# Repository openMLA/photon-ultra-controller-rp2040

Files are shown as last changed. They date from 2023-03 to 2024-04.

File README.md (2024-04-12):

> [!IMPORTANT]
> This repository has been archived as the implementation turned out to have too many limitations regarding memory. It will work for 2-bit images, but the newer approach is all around more capable. The replacement approach uses the DPI of a raspberry pi, and can be found at [openMLA/photon-ultra-controller](https://github.com/openMLA/photon-ultra-controller)

# Photon Ultra DLP controller

This repository contains PCB design files and code for a replacement mainboard for the [Anycubic Photon Ultra](https://www.anycubic.com/pages/anycubic-photon-ultra). 

The replacement board allows users to generate the signals required for the *DLP controller board* (designed by eViewTek) & DMD that comes with the photon ultra. It does not capture the full functionality of the Anycubic mainboard as it does not control the interface LCD, control the mechanics (stepper motor) or run any resin 3D printer slicer software. It **only** controls the DLP projector with an arbitrary 2-bit* 1240x720 image. Exposure time can be set per image.

This project might be of interest to you if you **own a photon ultra** and are interested in either

1. Using the photon ultra for PCB fabrication (use the DLP to expose a photoresist)
2. Are looking to use a DMD for other applications but are not ready to build your own controller board.

If you are interested in learning more about the Photon Ultra, you can find more information on [this photon ultra teardown blog post](https://nemoandrea.github.io/blog/Anycubic_DLP_teardown/). More images are available on request.

> If you have another board that uses the DMD chipset (e.g. Anycubic D2 or Mars 4 DLP), you can probably modify the project with minimal effort and get it to work for those boards too! (you would have to maybe have to adjust the traces to the FPC, and maybe tweak the physical connectors etc; but code and approach would be very similar)

### 💡 UV Patterns

> [!NOTE]  
> Due to RAM limitations (and my c programming skill limitations) the board can only display 2-bit images if you use the full resolution of the DMD. More RAM would solve this issue.

Below an example of the eViewTek board and optical engine controlled by the pico pio units, showing the OpenMLA project logo. Note that the pattern is 2-bit, so there are only 4 intensities (of which 1 is OFF).

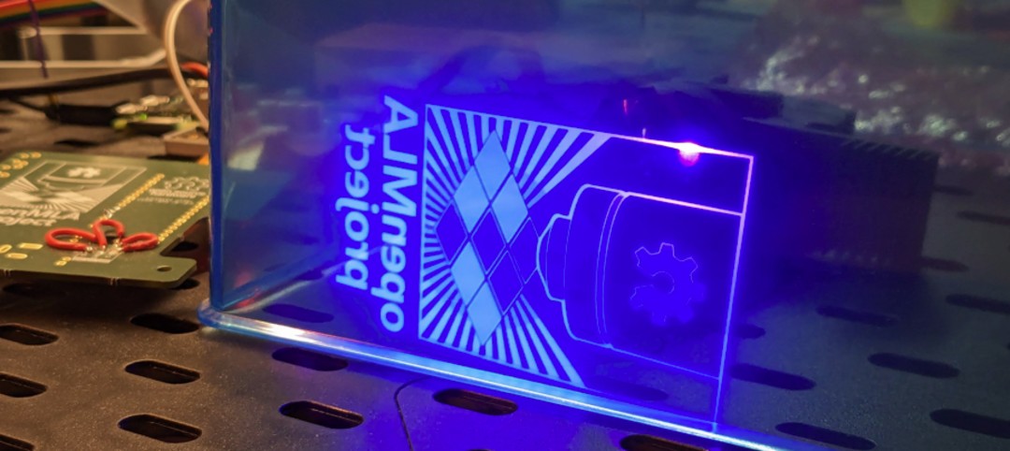
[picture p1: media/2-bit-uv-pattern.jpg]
image of projected UV light showing the logo of the openMLA project. The pattern is 2-bit.


Below another example of the 4 grayscale values that can be shown.

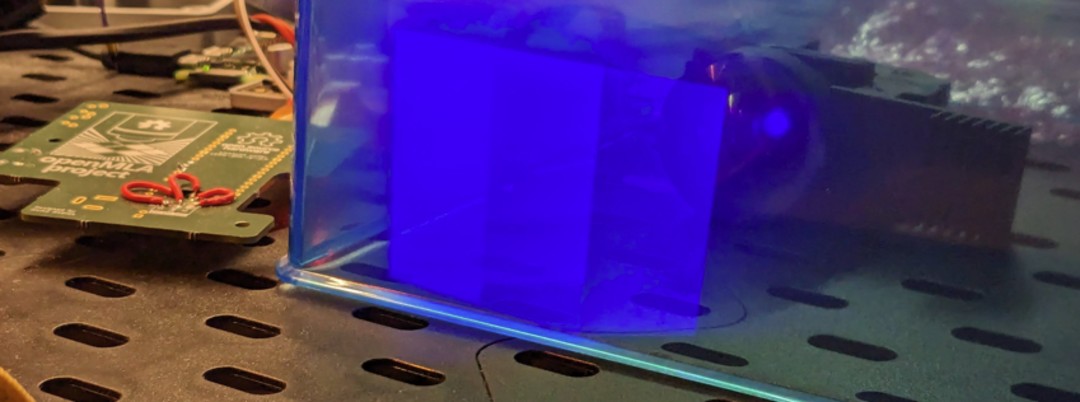
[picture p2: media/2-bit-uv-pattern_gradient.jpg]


### PCB

The PCB uses a Raspberry Pi Pico board as the central controller. The PIO blocks of the RP2040 generate the timing signals for the DLPC1438 chip on the DLP controller board.

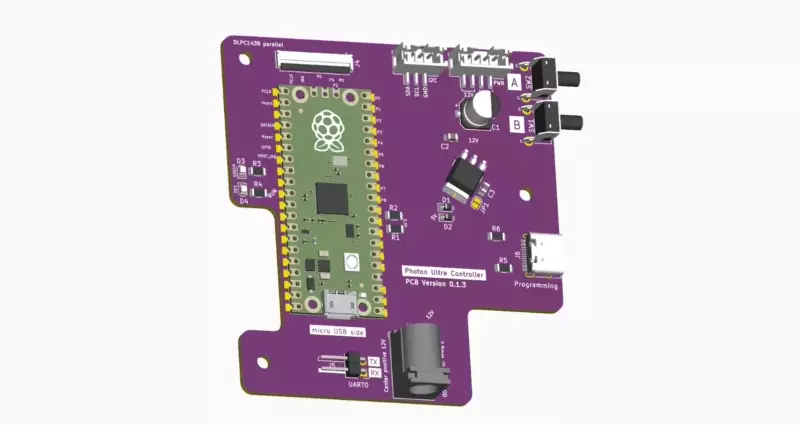
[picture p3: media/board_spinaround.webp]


### Using the board

The board is shaped to fit in the original mainboard space. The buttons, usb-c programming port and barrel jack are all accessible through the original Photon Ultra enclosure. This means you can use the original fittings, and everything in terms of cables should just fit.



Of course if you do not plan on using the DMD in the context of the photon ultra, you could easily redesign the board to be much more compact.

### Code

The code for this project is written in C, and unfortunately I am not a C programmer so it is very sloppy code. If you know of ways to make parts more elegant don't hesitate to make a pull request with changes.

More important than the code is the approach taken to power up and control the photon board, and more specifically the DLPC1438. A walkthrough of steps and gotchas can be found in [the guidelines](Guidelines.md). Most of it will also be mentioned in the code for the project, but having a separate document is more convenient.

The PIO implementation is a modified version of the nice [writeup by Hunter Adams](https://vanhunteradams.com/Pico/VGA/VGA.html#Code-organization).

To convert images for display, there is a simple python utility that converts a grayscale image into the right byte format for display. You can run it on the demo images to verify assembly.

### Context

This work was developed as part of the [openMLA project](https://github.com/openMLA), where the goal is to build an open hardware lithography system. Eventually an open hardware DLP controller board will be published as part of openMLA, but this represents an intermediate step. 

### Project TODO

* ✅ Establish I2C communication with DLPC1438 

* ✅ Verify UCB programming and linear regulator

* ❓ Verify 12V power delivery to board (should be fine as of version 0.1.4)

* ✅ Verify 51-pin connector and pinout is correct

* ✅ Verify (2-bit) images can be sent and projected

* ❓ Implement SPI interface for transferring images to the pico

* ❓ Minimise flickering

## Acknowledgements

The following KiCAD external libraries were used

* [Raspberry pi pico by ncarandini](https://github.com/ncarandini/KiCad-RP-Pico)

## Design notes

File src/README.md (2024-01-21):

## Running the DLP pico demo

To run the demo code on your pico, copy over the `build/DLP_pico.uf2` over to the pico.

### Building the demo code

I don't know a thing about compiling C stuff but given that this code is based on the nice [example code by Hunter Adams](https://vanhunteradams.com/Pico/VGA/VGA.html) most of the cmake stuff is already set up. To be able to build the project you may need to install the pico sdk. You can read more about this [in the official getting started guide](https://datasheets.raspberrypi.com/pico/getting-started-with-pico.pdf).

To build the project, head into the `build` directory and run

```
cmake .. -DPICO_BOARD=pico_w
```

and follow that up with 

```
make
```

Which should finally create the file `DLP_pico.uf2` that you can then use to program the pico. The `DLP_pico.uf2` file is also included in the repository to avoid having to go through the build process itself if you don't need to modify anything.

### Tools

In terms of hardware, I would suggest either using a [pico debug probe](https://www.raspberrypi.com/products/debug-probe/) to upload code, reset the pi and read the serial output, or a raspberry pi zero for the same application. You really don't want to have to unplug the board and press the reset button every time you want to try a new version of the code. Future versions of the board should make wiring SWD and UART readout easier.

I am not experienced enough with C to make a solid recommendation, but for the project I used Microsoft Visual Studio Code. With extensions:

* cmake
* serial monitor  (so we can get some information back from the pico)

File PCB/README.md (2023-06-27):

### PCB design

The design uses a Raspberry pi Pico W. A non-wireless version can also work but some of the scripts are to be built around wireless connectivity for data transfer. See the schematic (below and [as a pdf](schematic.pdf)) for more info.



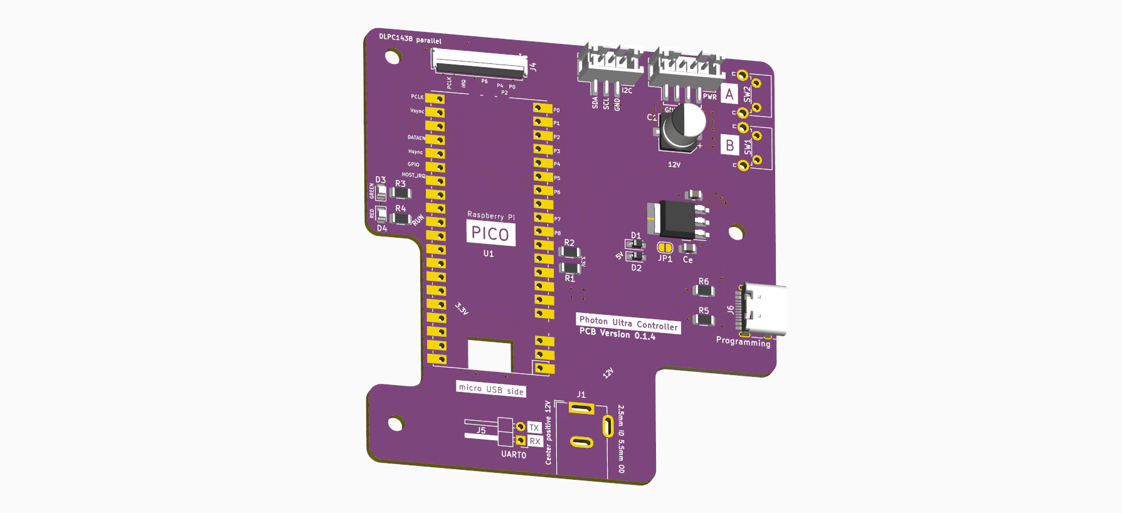
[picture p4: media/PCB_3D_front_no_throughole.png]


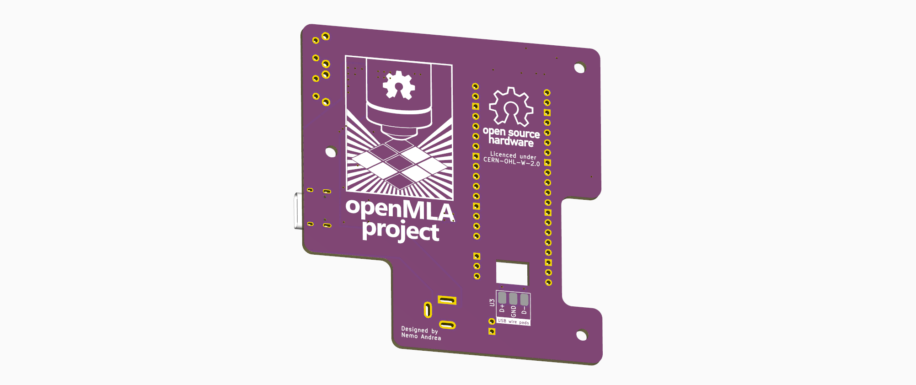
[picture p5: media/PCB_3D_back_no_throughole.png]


### Assembly

Most components are SMD, and the mouser links can be found in the basic [BOM](BOM.csv). In addition to the components of the BOM, you will also need some small wires to connect the USB data lines.

A solderpaste stencil might be worthwhile, as that FPC connector is pretty challenging (but not impossible) to handsolder.

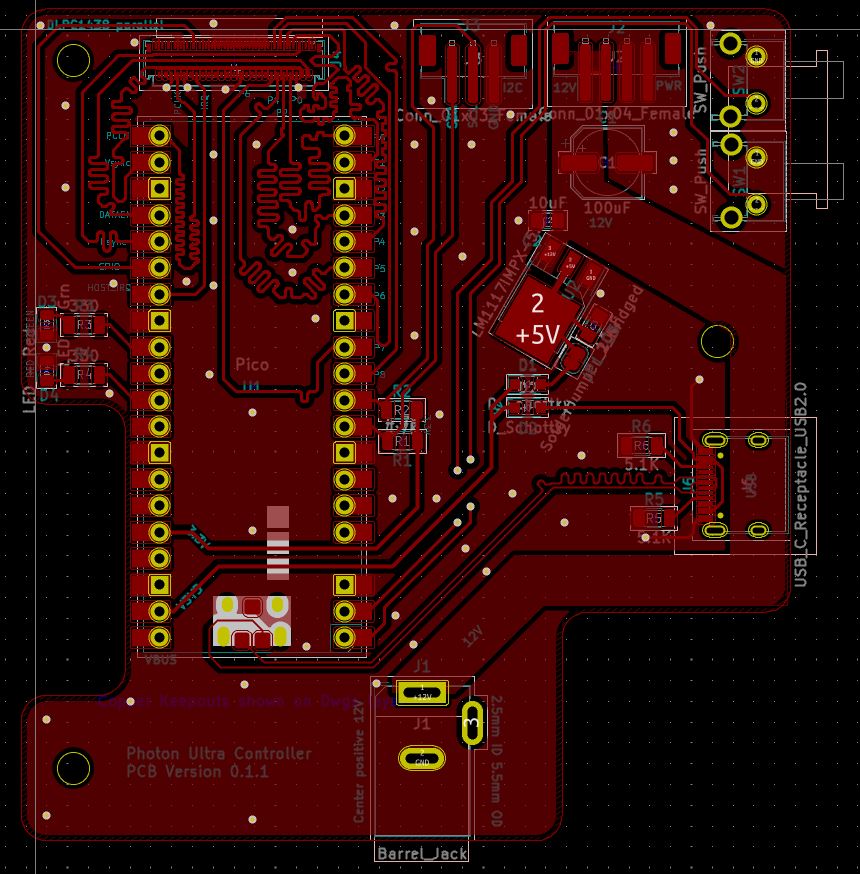
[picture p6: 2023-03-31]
media/PCB_preview.JPG

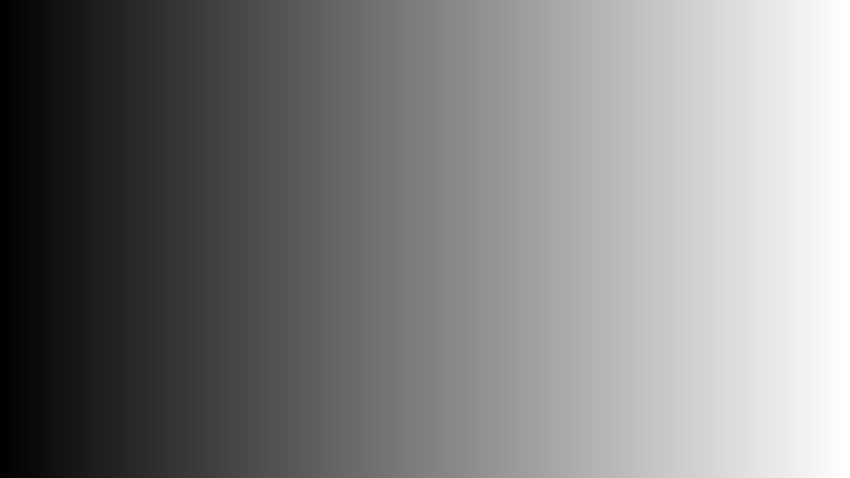
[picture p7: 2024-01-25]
utils/gradient_sample_image.tif

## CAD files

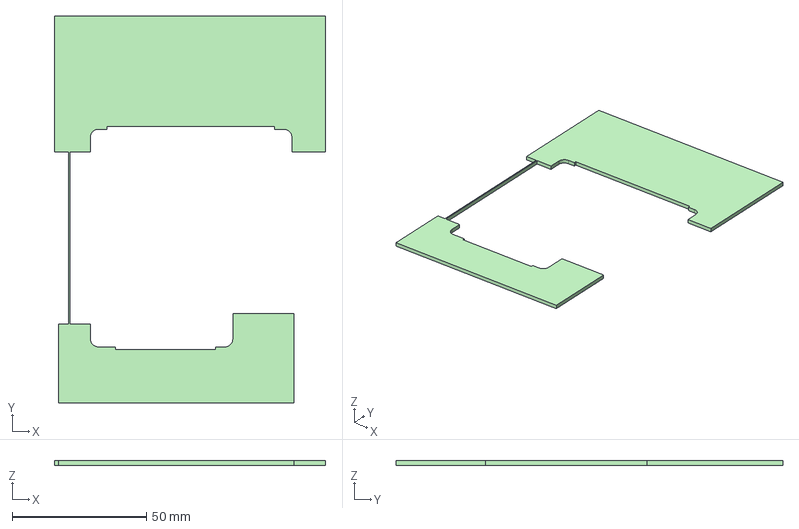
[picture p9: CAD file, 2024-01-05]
PCB/board-outline/board-outline-stencil-buffer.step
100.9 x 143.9 x 1.70 mm

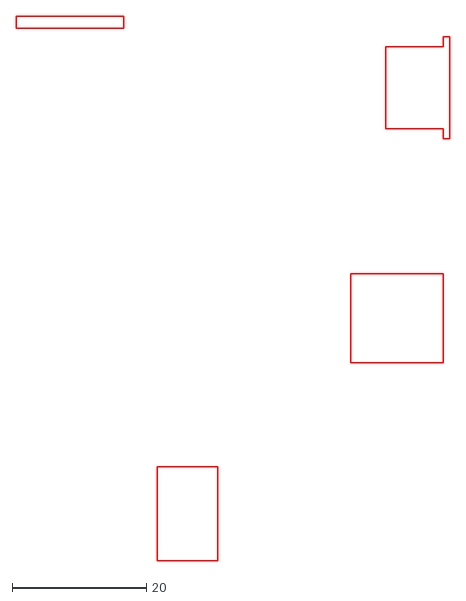
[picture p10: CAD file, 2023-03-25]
PCB/board-outline/board-outline-bits.dxf
64.5 x 81.1

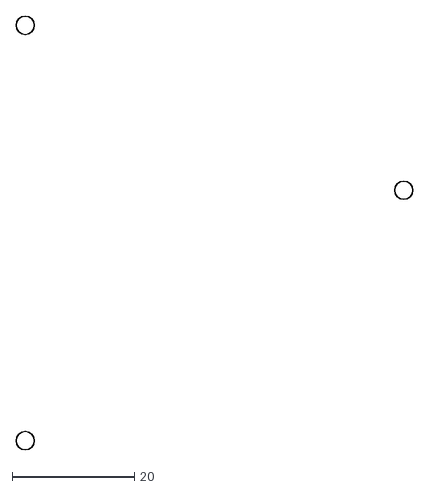
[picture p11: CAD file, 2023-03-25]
PCB/board-outline/board-outline-holes.dxf
65.0 x 71.0

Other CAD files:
PCB/board-outline/board-outline.FCStd
PCB/board-outline/board-outline.dxf

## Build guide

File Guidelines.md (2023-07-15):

## Photon Ultra board & DLPC1438 guidelines

> This section will outline some of the guidelines, and excerpts from the datasheets that are relevant to both specifically the Photon Ultra board and the DLPC1438 in general.

Suggested documents to familiarise yourself with

1. [The DLPC1438 datasheet](https://www.ti.com/lit/ds/symlink/dlpc1438.pdf?ts=1689232218137)
2. [The DLPC1438 programming guide (describes the I2C stuff)](https://www.ti.com/lit/ug/dlpu111/dlpu111.pdf?ts=1689282051632&ref_url=https%253A%252F%252Fwww.google.com%252F)
3. [The raspberry pi pico c SDK](https://datasheets.raspberrypi.com/pico/raspberry-pi-pico-c-sdk.pdf)

### Startup sequence

In the datasheet for the  `DLPC1438` there are multiple sections containing info about the startup sequence:

1. section 7.3.3
2. section 9.2 & 9.3

The main gist of it is that to power on you must both:

1. Provide power to the photon ultra board
2. Keep GPIO_08 (on DLPC1438) (a.k.a. PROJ_ON) high

The controller will then run through a reset/bootup cycle and eventually let you know it is done by pulling HOST_IRQ low.

After HOST_IRQ is low you can start the i2c bus and start talking to the DLPC1438.

> 🖼 Figure 9-1 of the datasheet nicely summarises this.

### I2C notes

For whatever reason (probably a I2C address conflict) Anycubic/eViewTek has changed the default i2c adress of the DLPC1438 on the Ultra's board from `0x36` to `0x1B`. 

> I assume this will be the same for all the boards, but if not you can connect power and the FPC to the ultra's mainboard and only the i2c line to the pico board and then after power on of the Ultra mainboard run an i2c scan script to find out the address of the DLPC1438.

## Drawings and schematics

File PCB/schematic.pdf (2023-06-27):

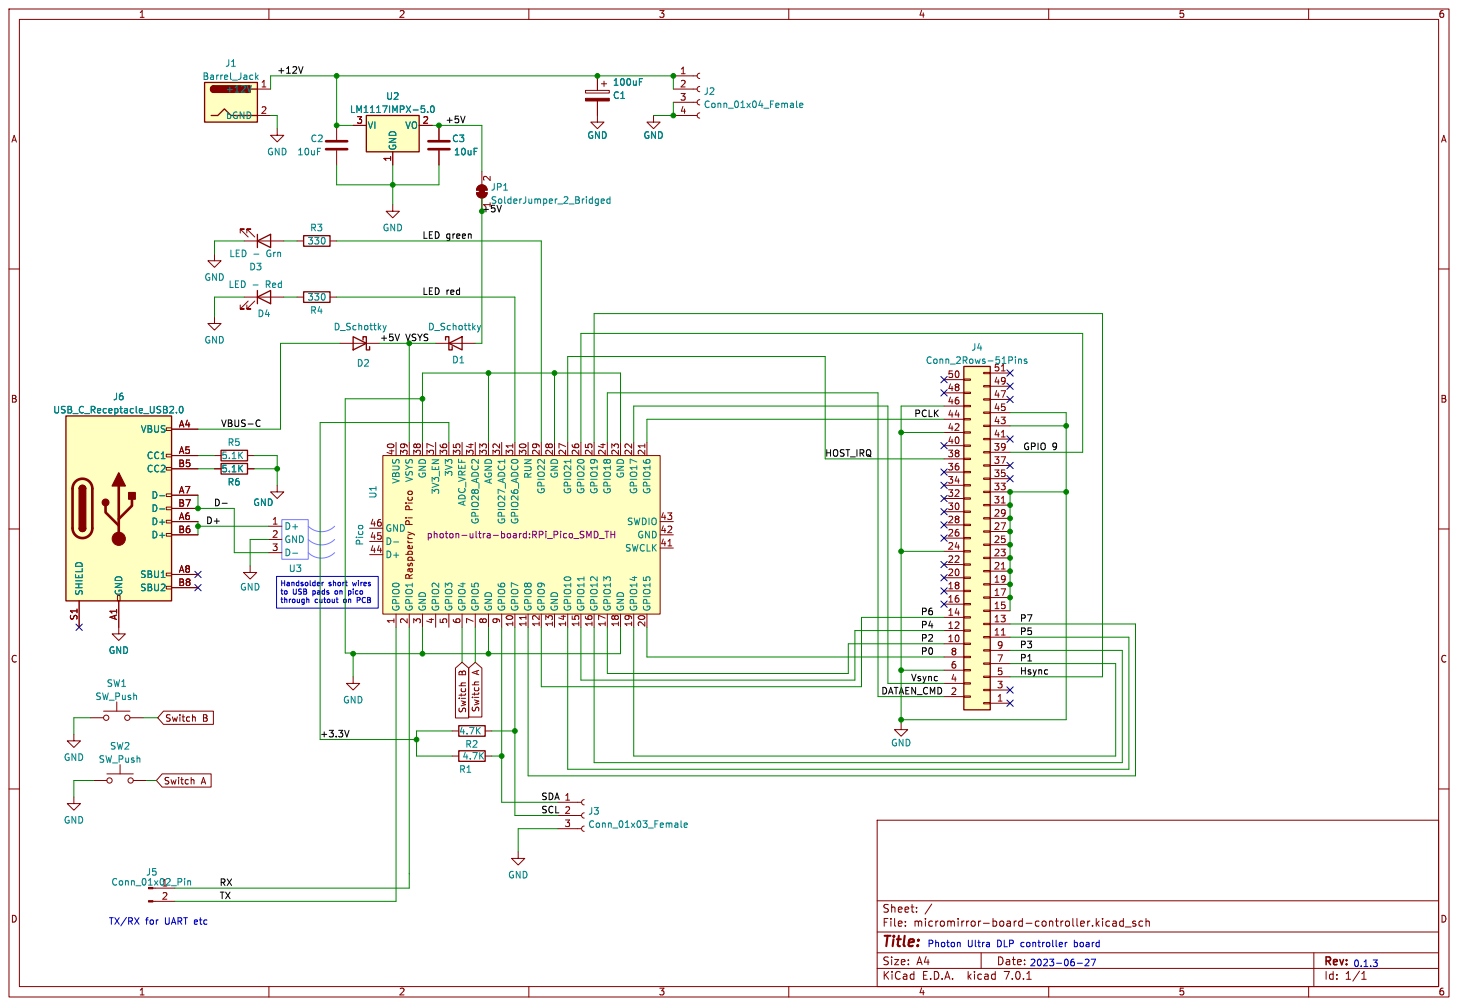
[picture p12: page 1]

to USB pads on pico
through cutout on PCB

Id: 1/1 Title: File: micromirror-board-controller.kicad_sch Sheet: /

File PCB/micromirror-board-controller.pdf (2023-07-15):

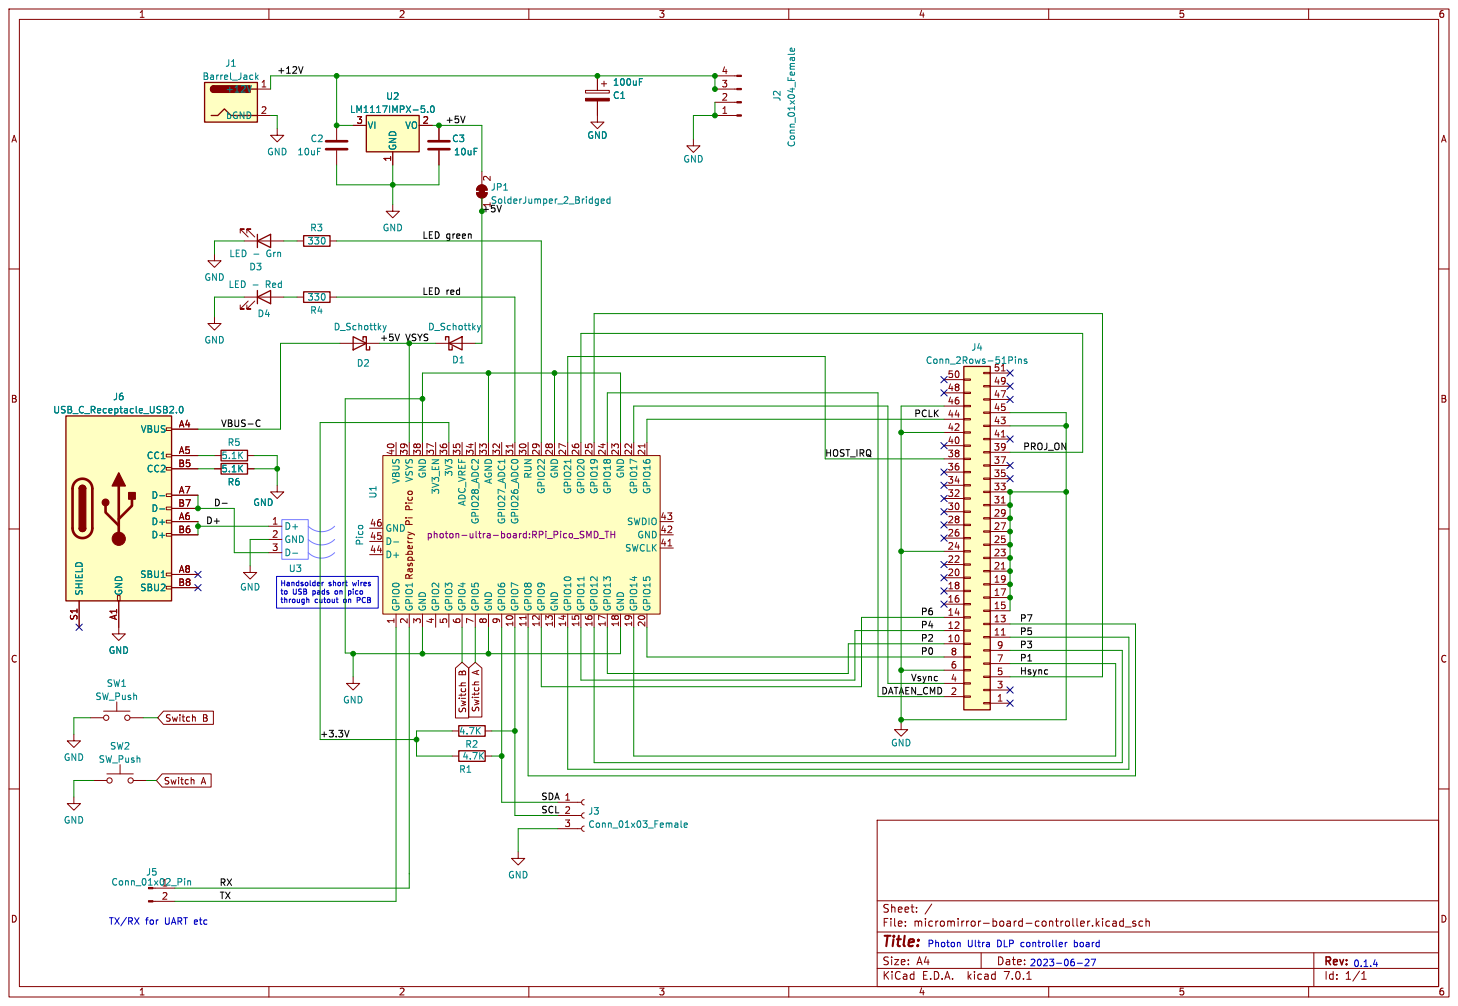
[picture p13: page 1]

to USB pads on pico

Id: 1/1 Title: File: micromirror-board-controller.kicad_sch Sheet: /

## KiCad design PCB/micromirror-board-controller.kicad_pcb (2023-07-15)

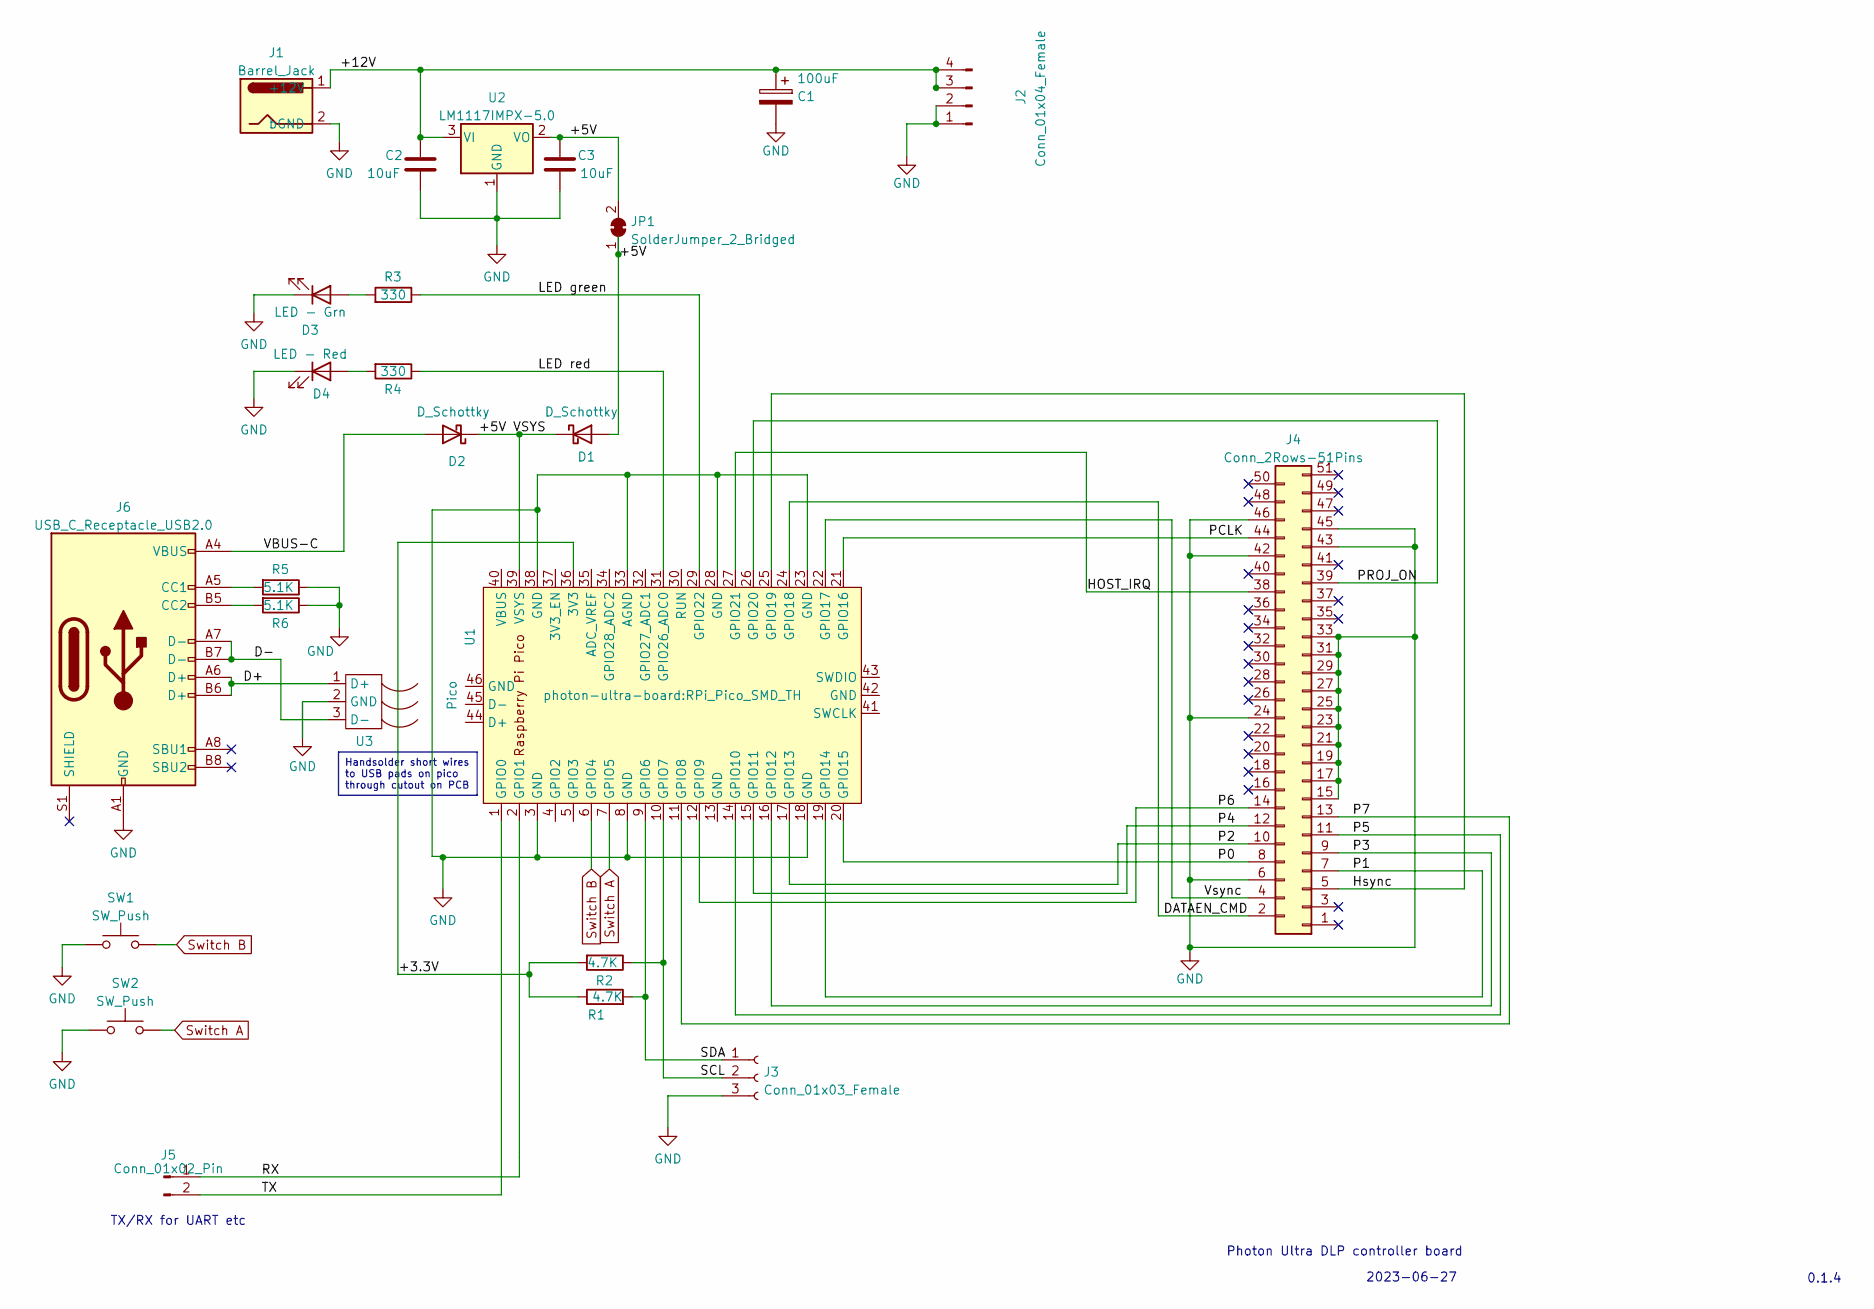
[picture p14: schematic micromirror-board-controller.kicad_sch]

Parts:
C1: 100uF; CP_Elec_6.3x7.7
C2, C3: 10uF; C_0805_2012Metric_Pad1.18x1.45mm_HandSolder
D1, D2: D_Schottky; D_SOD-323_HandSoldering
D3: LED - Grn; LED_0805_2012Metric
D4: LED - Red; LED_0805_2012Metric
J1: Barrel_Jack; BarrelJack_GCT_DCJ200-10-A_Horizontal
J2: Conn_01x04_Female; JST_PH_B4B-PH-SM4-TB_1x04-1MP_P2.00mm_Vertical
J3: Conn_01x03_Female; JST_PH_B3B-PH-SM4-TB_1x03-1MP_P2.00mm_Vertical
J4: Conn_2Rows-51Pins; Molex_502250-5191_2Rows-51Pins-1MP_P0.60mm_Horizontal
J5: Conn_01x02_Pin; PinHeader_1x02_P2.54mm_Horizontal
J6: USB_C_Receptacle_USB2.0; USB_C_Receptacle_HRO_TYPE-C-31-M-12
JP1: SolderJumper_2_Bridged; SolderJumper-2_P1.3mm_Bridged_RoundedPad1.0x1.5mm
R1, R2: 4.7K; R_1206_3216Metric
R3, R4: 330; R_1206_3216Metric
R5, R6: 5.1K; R_1206_3216Metric
SW1, SW2: SW_Push; SW_Tactile_SPST_Angled_PTS645Vx83-2LFS
U1: Pico; RPi_Pico_SMD_TH
U2: LM1117IMPX-5.0; TO-252-3_TabPin2
U3: usb-handsolder-pads

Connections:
/+3.3V: R1.1, R2.2, U1.36 (3V3)
/+5V: C3.1, D1.2 (A), JP1.1 (A), JP1.2 (B), U2.2 (VO); also elsewhere on the board
/+5V VSYS: D1.1 (K), D2.1 (K), U1.39 (VSYS)
/+12V: C1.1, C2.1, J1.1 (+12V), J2.3, J2.4, U2.3 (VI)
/D+: J6.A6 (D+), J6.B6 (D+), U3.1 (D+)
/D-: J6.A7 (D-), J6.B7 (D-), U3.3 (D-)
/DATAEN_CMD: J4.2 (DATAEN), U1.24 (GPIO18)
/HOST_IRQ: J4.38 (HOST_IRQ), U1.27 (GPIO21)
/Hsync: J4.5 (Hsync), U1.25 (GPIO19)
/LED green: R3.1, U1.29 (GPIO22)
/LED red: R4.1, U1.31 (GPIO26_ADC0)
/P0: J4.8 (P0), U1.20 (GPIO15)
/P1: J4.7 (P1), U1.19 (GPIO14)
/P2: J4.10 (P2), U1.17 (GPIO13)
/P3: J4.9 (P3), U1.16 (GPIO12)
/P4: J4.12 (P4), U1.15 (GPIO11)
/P5: J4.11 (P5), U1.14 (GPIO10)
/P6: J4.14 (P6), U1.12 (GPIO9)
/P7: J4.13 (P7), U1.11 (GPIO8)
/PCLK: J4.44 (PCLK), U1.21 (GPIO16)
/PROJ_ON: J4.39 (GPIO_9), U1.26 (GPIO20)
/RX: J5.1, U1.2 (GPIO1)
/SCL: J3.2 (SCL), R2.1, U1.10 (GPIO7)
/SDA: J3.1 (dGND), R1.2, U1.9 (GPIO6)
/TX: J5.2, U1.1 (GPIO0)
/VBUS-C: D2.2 (A), J6.A4 (VBUS), J6.A9 (VBUS), J6.B4 (VBUS), J6.B9 (VBUS)
/Vsync: J4.4 (Vsync), U1.22 (GPIO17)
GND: C1.2, C2.2, C3.2, D3.1 (K), D4.1 (K), J1.2 (bGND), J2.1, J2.2, J3.3 (SDA), J4.6 (GND), J4.15 (GND), J4.17, J4.19, J4.21, J4.23, J4.24, J4.25, J4.27, J4.29, J4.31, J4.33, J4.42 (GND), J4.43 (GND), J4.45 (GND), J4.46 (GND), J6.A1 (GND), J6.A12 (GND), J6.B1 (GND), J6.B12 (GND), R5.1, R6.1, SW1.1, SW2.1, U1.3 (GND), U1.8 (GND), U1.18 (GND), U1.23 (GND), U1.28 (GND), U1.33 (AGND), U1.38 (GND), U2.1 (GND), U3.2 (GND); also elsewhere on the board
unnamed: D3.2 (A), R3.2
unnamed: D4.2 (A), R4.2
unnamed: J6.A5 (CC1), R5.2
unnamed: J6.B5 (CC2), R6.2
Switch A: SW2.2, U1.7 (GPIO5)
Switch B: SW1.2, U1.6 (GPIO4)

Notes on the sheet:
Handsolder short wires to USB pads on pico through cutout on PCB
TX/RX for UART etc
Photon Ultra DLP controller board
2023-06-27
0.1.4

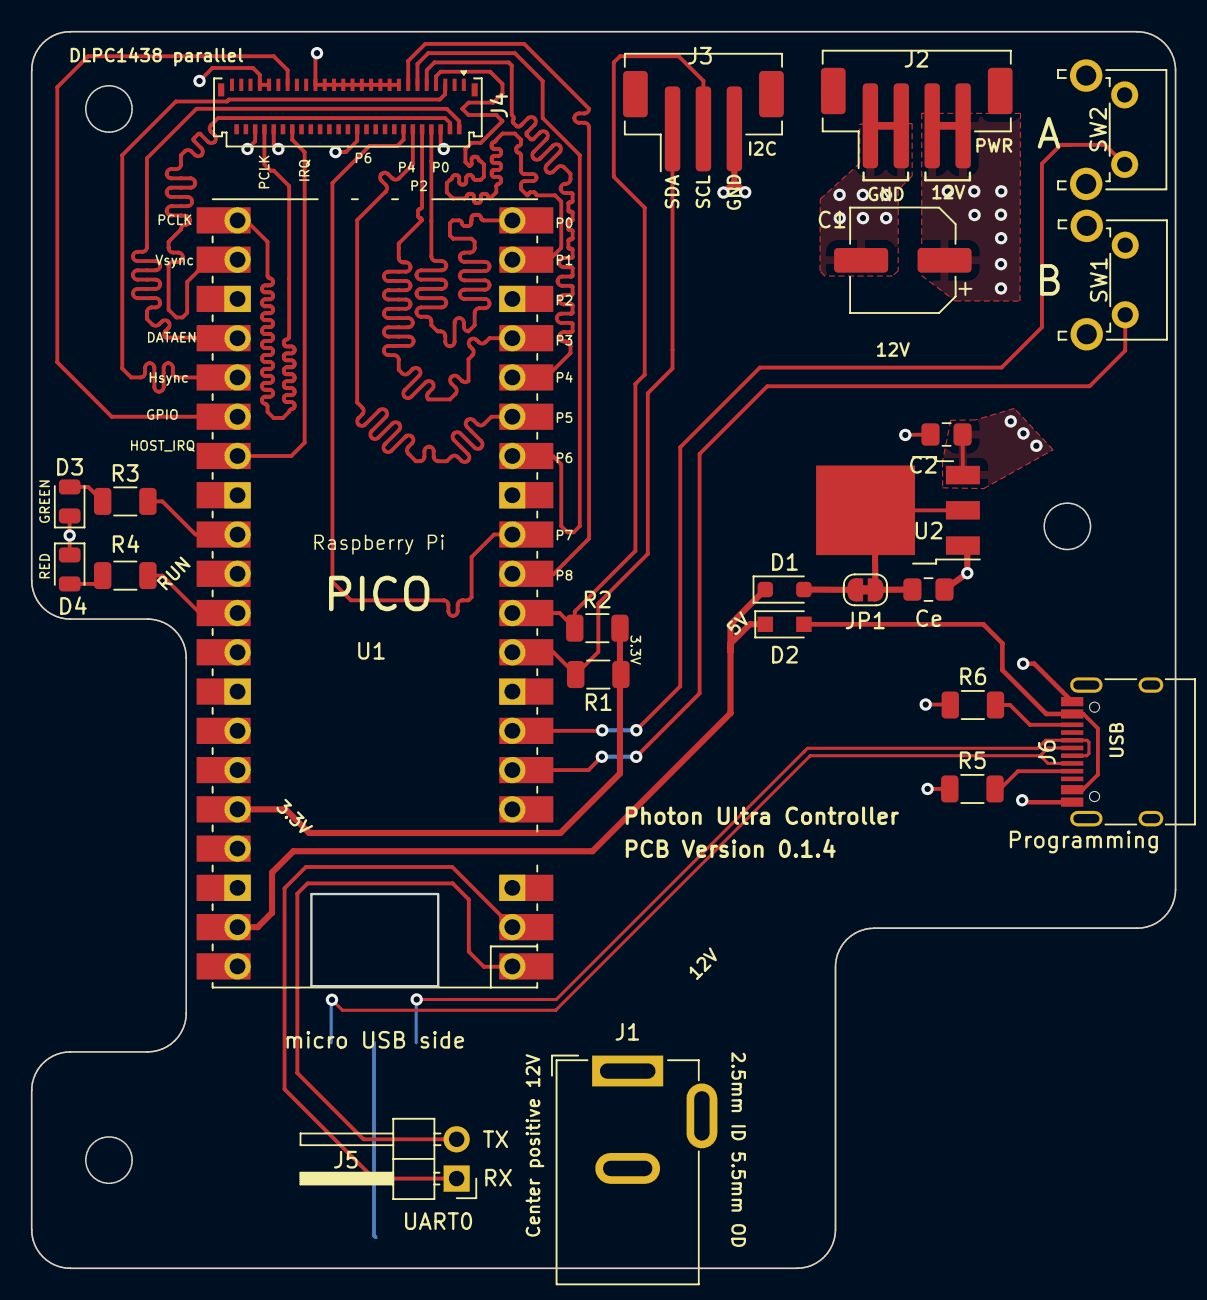
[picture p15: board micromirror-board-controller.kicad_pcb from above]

Board: 2 copper layers, 74.0 x 80.0 mm, 25 parts (1 on the bottom side), 34 nets.

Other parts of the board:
Ce: 10uF; C_0805_2012Metric_Pad1.18x1.45mm_HandSolder

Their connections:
/+5V: Ce.1; also elsewhere on the board
GND: Ce.2; also elsewhere on the board

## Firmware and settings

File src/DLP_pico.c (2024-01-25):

/**
 * Nemo Andrea (nemoandrea@outlook.com)
 * Based on demo code by  Hunter Adams (vha3@cornell.edu)
 * 
 * Texas Instruments DLPC1438 video signal generator
 * Uses PIO-assembly of RP2040
 *
 * HARDWARE CONNECTIONS
 *  - GPIO 19 ---> Hsync
 *  - GPIO 18 ---> DATAEN_CMD (data valid) 
 *  - GPIO 17 ---> Vsync
 *  - GPIO 16 ---> PCLK (pixel clock)
 *  - GPIO 8:15 ---> Pdata[0:8] (pixel data 8bit grayscale)
 *
 * RESOURCES USED
 *  - PIO state machines 0, 1, 2 and 3 on PIO instance 0
 *  - DMA channels 0 and 1
 *  - 230.4 kBytes of RAM (for pixel color data)
 *
 */
#include <stdio.h>
#include <assert.h>
#include "pico/stdlib.h"
#include "hardware/pio.h"
#include "hardware/dma.h"
#include "hardware/i2c.h"
#include "hardware/gpio.h"

#include "test_image.h" // Include the header file

// Our assembled programs:
// Each gets the name <pio_filename.pio.h>
#include "hsync.pio.h"
#include "vsync.pio.h"
#include "pxl.pio.h"
#include "pxl_clk.pio.h"

const int PROJ_ON_GPIO = 20;  // physical pin nr 26
const int HOST_IRQ_GPIO = 21;  // physical pin nr 27  

const uint LED_PIN_G = 26;  // GPIO 26
const uint LED_PIN_R = 22;  // GPIO 26
const uint SDA_PIN = 6; // GPIO 6
const uint SCL_PIN = 7; // GPIO 7

static uint16_t exposure_time = 200;

enum ProjectorMode {
    TESTPATTERN,
    SPLASHSCREEN,
    EXTERNALPRINT,
    STANDBY
};

enum LightState {
    OFF,
    ON
};

//////// i2c config (max freq 100 kHz)

// we define the i2c address of the DLPC1438. For whatever reason (I guess conflict with other
// i2c devices on the mainboard) eViewTek have changed the i2c address to 0x1B, from the 
// factory setting of 36h. I assume this will be the same for all boards. 
const int DLPC_addr = 0x1B;  

void initialise_DLPC() {  
    gpio_init(PROJ_ON_GPIO);
    gpio_set_dir(PROJ_ON_GPIO, GPIO_OUT);
    gpio_init(HOST_IRQ_GPIO);
    gpio_set_dir(HOST_IRQ_GPIO, GPIO_IN);
    bool current_IRQ_state = 0;

    printf(">> Attempting to initialise the DLPC1438...\n\n");

    // HOST_IRQ will be pulled HIGH by the pullup on eViewTek board
    // but in theory it could also be LOW at this time
    current_IRQ_state = gpio_get(HOST_IRQ_GPIO);  
    printf("HOST_IRQ at startup is: %d\n", current_IRQ_state);
    

    // to signal to the DLPC1438 that we want to start up, we must set PROJ_ON high
    printf("Setting PROJ_ON (DLPC1436:GPIO8) HIGH...\n");
    gpio_put(PROJ_ON_GPIO, 1);  // this will let the DLPC1438 know we want to go, go go

    // now we must let the DLPC1438 run through its initialisation cycle
    // it will let us know it is done by pulling HOST_IRQ low (~500ms)
    printf("Waiting for HOST_IRQ LOW...\n");

    bool last_IRQ_state = 0;
    bool transition = 0;
    int count = 0;
    int sleeptime = 50;  // in ms 

    // TODO: the HOST_IRQ signal is 1.8V when high; hard to interpret on the pico; right
    // on the threshold of detectable voltage. Code below assumes we can reliably distinguish
    // between 0 and 1.8V. Alternative: wait for 1 s and assume it is ready.

    // while (!transition) {
    //     sleep_ms(sleeptime);
    //     current_IRQ_state = gpio_get(HOST_IRQ_GPIO);  
    //     //printf("HOST IRQ IS: %d\n", current_IRQ_state);
    //     if ((last_IRQ_state == 1) && (current_IRQ_state == 0)) { transition = 1; }
    //     last_IRQ_state = current_IRQ_state;
    //     count += 1;
    // }  // typically this takes ~650ms

    sleep_ms(1000);  // makeshift solution if the HOST_IRQ based approach does not work.

    printf("HOST_IRQ has been pulled low by DLPC1438, %dms after PROJ_ON signal\n", count*sleeptime);
    
    // now that HOST_IRQ is low we can start i2c communication. Lets give it 100ms to be safe
    sleep_ms(100);
    printf("DLPC1438 is ready for I2C communication!");
}

// set up i2c hardware on pico
void configure_i2c() {
    printf("\n>> setting up I2C...\n\n");
    
    gpio_set_function(SDA_PIN, GPIO_FUNC_I2C);
    gpio_set_function(SCL_PIN, GPIO_FUNC_I2C); 
    //gpio_pull_up(SDA_PIN);  // Don't need these since we have hardware pullup on the PCB
    //gpio_pull_up(SCL_PIN);  // Don't need these since we have hardware pullup on the PCB
    i2c_init(i2c1, 40 * 1000);  // DLPC1438 supports up to 100KHz; we use i2c HW block 0
    printf("i2c should be ready!\n");
}

/// TEMPORARY TODO: remove
bool reserved_addr(uint8_t addr) {
    return (addr & 0x78) == 0 || (addr & 0x78) == 0x78;
}

void scan_i2c() {
    printf("\nI2C Bus Scan\n");
    printf("   0  1  2  3  4  5  6  7  8  9  A  B  C  D  E  F\n");

    for (int addr = 0; addr < (1 << 7); ++addr) {
        if (addr % 16 == 0) {
            printf("%02x ", addr);
        }

        // Perform a 1-byte dummy read from the probe address. If a slave
        // acknowledges this address, the function returns the number of bytes
        // transferred. If the address byte is ignored, the function returns
        // -1.

        // Skip over any reserved addresses.
        int ret;
        uint8_t rxdata[3];
        if (reserved_addr(addr))
            ret = PICO_ERROR_GENERIC;
        else
            ret = i2c_read_blocking(i2c1, addr, rxdata, 1, false);

        printf(ret < 0 ? "." : "@");
        printf(addr % 16 == 15 ? "\n" : "  ");
    }
    printf("Done.\n");
}

// can we actually see AND talk to DLPC1438 over i2c?
void check_i2c_communication() {
    // Can we see the DLPC1438?
    scan_i2c();
    sleep_ms(500);

    // Can we talk to the DLPC1438?
    int ret;
    uint8_t rxdata;
    ret = i2c_read_blocking(i2c1, DLPC_addr, &rxdata, 1, false); 
    printf(ret < 0 ? "Could not connect to DLPC1438 over i2c\n" : "Found DLPC1438 on i2c\n");
    if (ret >= 0) { 
        gpio_put(LED_PIN_R, 1);  // turn on LED so we know we are connected.
    }
}

void i2c_write(uint8_t addr, uint8_t *data, int length) {
    // note that length is here the length of data (so excluding the addr)
    uint8_t send_data[length+1];  // but we we must combine [addr, data...] to send over

    send_data[0] = addr;

    int i = 0;
    for (i = 0; i < length; i++) {
        send_data[i+1] = data[i];
    }

    printf("(i2c-send) raw data: ");  // just for my sanity

    for (int i = 0; i < sizeof send_data / sizeof send_data[0]; i++) {
        printf("%x ", send_data[i]);
    }
    printf("\n");

    i2c_write_blocking(i2c1, DLPC_addr, send_data, length+1, false);
}

// read I2C data back
// TODO: there is a strange issue where the first byte is a mystery byte
// and it is not clear to me atm why this is returned, or what it represents.
// for now I just ask for data at length+1 and print  only data[1:end]
void i2c_read(uint8_t addr, uint8_t length, char* message) {
    uint8_t data_in[length+1];

    i2c_write_blocking(i2c1, DLPC_addr, &addr, 1, true);
    i2c_read_blocking(i2c1, DLPC_addr, data_in, length+1, false);

    printf(message);
    for (int i = 0; i < length; i++) {
        printf("%x \n", data_in[i]);
    }
}

void switch_projector_mode(enum ProjectorMode mode) {
    
    uint8_t addr = 0x05;  // i2c addr for mode switch
    uint8_t mode_value;
    switch(mode) {
        case(0):
            printf("> Switching to Test Pattern mode (0x01)\n");
            mode_value = 0x01;
            break;
        case(1):
            printf("> Switching to Splash-Screen mode (0x02)\n");
            mode_value = 0x02;    
            break;
        case(2):
            printf("> Switching to External Print mode (0x06)\n");
            mode_value = 0x06;
            break;
        case(3):
            printf("> Switching to Standby mode (0xFF)\n");
            mode_value = 0xFF;
            break;
    }

    // checking initial state:
    i2c_read(0x06, 1, "Mode before switching: ");

    uint8_t data[] = {mode_value};
    i2c_write(addr, data, 1);

    // temporary: check that we switched ok  --> works fine
    i2c_read(0x06, 1, "Mode after switching: ");
}

void curtain_flood_exposure(int duration, int count) {
    // simple utility function that will do a flood exposure (all pixels on max)
    // for a certain <duration> (in ms) and repeated a <count> number of times.
    // useful for testing communication.

    // note that projector cannot be in standby mode for this to work. Try Testpattern.

    i2c_read(0x17, 1, "Base curtain settings: "); //TODO: remove
    uint8_t curtain[1];

    for (int i = 0; i < count; i++) {
        // flood exposure ON
        curtain[0] = 0b00001111;
        i2c_write(0x16, curtain, 1);
        sleep_ms(duration);
        // flood exposure OFF
        curtain[0] = 0b00000000;
        i2c_write(0x16, curtain, 1);
        sleep_ms(duration);
    }
}

void configure_external_print(){  // see section 3.3.6 (and 3.3.1) of programming guide
    // in this step we set both the transfer fuction gamma and select which LED to use
    printf("\n>> Configuring External Print mode...\n\n");

    // temporary: checking initial state:
    i2c_read(0xA9, 2, "intial gamma/led config settings: \n");
    sleep_ms(100);

    // write the new values to register (actually configure the DLPC1438)
    int gamma = 0x00;  // we want the linear kind (also used by Anycubic)
    // Select which LED to use. b(7:2) are reserved. The final 3 bits are toggles for LED 3,2,1 
    int led_select = 0b00000100;  // one LED at a time. Anyubic board says we need LED3.
    uint8_t data[] = {gamma, led_select};  
    i2c_write(0xA8, data, 2);

    i2c_read(0xA9, 2, "new gamma/led config settings: \n");
    sleep_ms(100);
}

// programming guide section 3.3.8 & 9
// exposure values taken from Anycubic Board's I2C commands during test patterns
void switch_light_state(enum LightState light_on) { 
    uint8_t print_control, dark_frames_LSB, dark_frames_MSB, exp_frames_LSB, exp_frames_MSB;

    if (light_on) {
        printf("[!UV!] Switching Projector Light ON\n");
        // "External Print Control" byte; b(7:1) reserved; 0 is START, 1 is STOP.
        print_control   = 0b00000000;  // 1 for light off, 0 for light on
        dark_frames_LSB = 0x03; 
        dark_frames_MSB = 0x00; 
        exp_frames_LSB  = 0xFF;  // if both exp_frames are 0xFF the LED will stay on indefinitely
        exp_frames_MSB  = 0xFF;  // and turning off is then done by sending this command with 
                                        // print_control being 0b00000001 
    } else {
        printf("Switching Projector Light OFF\n");
        print_control   = 0b00000001;  // 1 for light off, 0 for light on
        dark_frames_LSB = 0x00; 
        dark_frames_MSB = 0x00; 
        exp_frames_LSB  = 0x00;  
        exp_frames_MSB  = 0x00;  
    }

    uint8_t data[] = {print_control, dark_frames_LSB, dark_frames_MSB, exp_frames_LSB, exp_frames_MSB}; 
    sleep_ms(30);  // give it a little moment 
    i2c_write(0xC1, data, 5);

    // i2c_read the 0xC2 register never seems to actually return logical numbers
    // I assume there is something wrong on the firmware side. The effect of the write command
    // is okay though.
    // i2c_read(0xC2, 5, "New Dark and Exposed frame settings: \n");
}

void set_illumination_PWM(unsigned short PWM_value) {
    // Set the PWM for the LED source. Note that the resolution is only 10 bit (so 6 unused bits)
    // We only consider LED 3 (byte 5,6) since that is the LED source we use

    // The anycubic board uses 0xB4 (quite far from the max) during setup.

    uint8_t LSByte = PWM_value & 0xFF;
    uint8_t MSByte = (PWM_value >> 8) & 0xFF;

    uint8_t data[] = {0, 0, 0, 0, LSByte, MSByte};
    i2c_write(0x54, data, 6);
    i2c_read(0x55, 6, "Set LED PWM settings: \n");
}

void set_image_orientation(bool flip_short_axis, bool flip_long_axis) {
    uint8_t shifted_sa = (flip_short_axis << 2);
    uint8_t shifted_la = (flip_long_axis << 1); 
    uint8_t orientation_setting = (shifted_sa | shifted_la);
    uint8_t data[1] = {orientation_setting};

    i2c_write(0x14, data, 1);
    i2c_read(0x15, 1, "Set image orientation settings: \n");
}

void configure_test_pattern_settings(uint8_t pattern_idx) {

    i2c_read(0x0C, 6, "old test pattern settings: \n");

    uint8_t pattern_select = 0b10000111;  // b(6:4) reserved
    // parameters (effect depends on selected pattern)
    // note that if a parameter is not used by pattern then the bytes will not be set
    // and reading back the value after setting will yield 0x00
    uint8_t param_1 = 0; 
    uint8_t param_2 = 240;
    uint8_t param_3 = 0;  
    uint8_t param_4 = 240;

    // TODO: decipher the meaning of byte 2; its not clear if it is actually reserved...
    // will set to 0x00 for now.

    uint8_t test_pattern_settings[6] = {pattern_select, 0x00, param_1, param_2, param_3, param_4};

    i2c_write(0x0B, test_pattern_settings, 6);

    i2c_read(0x0C, 6, "new test pattern settings: \n");
}

void intialise_DLP_test_pattern() {
    // for some reason the intial pattern seems to be a checkerboard,
    // but the i2c registers all read 0. Might be a special case...
    switch_projector_mode(TESTPATTERN);
    sleep_ms(200);

    // first we must configure the test pattern mode BEFORE activating it
    configure_test_pattern_settings(0);

    // now we can switch to test pattern mode
    printf(">>> MODE AT STARTUP\n");
    sleep_ms(200);

    switch_projector_mode(TESTPATTERN);
}
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
int main() {
    // Initialize stdio
    stdio_init_all();

    ////////////////////////////////////////////////////////////////////////////////////////////////
    // ===========================-== PIO Stuff ====================================================
    ////////////////////////////////////////////////////////////////////////////////////////////////

    // Choose which PIO instance to use (there are two instances, each with 4 state machines)
    PIO pio = pio0;

    // Our assembled program needs to be loaded into this PIO's instruction
    // memory. This SDK function will find a location (offset) in the
    // instruction memory where there is enough space for our program. We need
    // to remember these locations!
    //
    // We only have 32 instructions to spend! If the PIO programs contain more than
    // 32 instructions, then an error message will get thrown at these lines of code.
    //
    // The program name comes from the .program part of the pio file
    // and is of the form <program name_program>
    uint hsync_offset = pio_add_program(pio, &hsync_program);
    uint vsync_offset = pio_add_program(pio, &vsync_program);
    uint pxl_offset = pio_add_program(pio, &pxl_program);
    uint clk_offset = pio_add_program(pio, &pxl_clk_program);

    // Manually select a few state machines from pio instance pio0.
    uint hsync_sm = 0;
    uint vsync_sm = 1;
    uint pxl_sm = 2;
    uint clk_sm = 3;

    // Call the initialization functions that are defined within each PIO file.
    // Why not create these programs here? By putting the initialization function in
    // the pio file, then all information about how to use/setup that state machine
    // is consolidated in one place. Here in the C, we then just import and use it.
    hsync_program_init(pio, hsync_sm, hsync_offset, HSYNC);
    vsync_program_init(pio, vsync_sm, vsync_offset, VSYNC);
    pxl_program_init(pio, pxl_sm, pxl_offset, BASE_PXL_PIN, DATAEN_CMD);
    pxl_clk_program_init(pio, clk_sm, clk_offset, PXL_CLK);


    /////////////////////////////////////////////////////////////////////////////////////////////////////
    // ===========================-== DMA Data Channels =================================================
    /////////////////////////////////////////////////////////////////////////////////////////////////////

    // DMA channels - 0 sends color data, 1 reconfigures and restarts 0
    int pxl_chan_0 = 0;
    int pxl_chan_1 = 1;

    // Channel Zero (sends color data to PIO VGA machine)
    dma_channel_config c0 = dma_channel_get_default_config(pxl_chan_0);  // default configs
    channel_config_set_transfer_data_size(&c0, DMA_SIZE_8);              // 4-bit txfers
    channel_config_set_read_increment(&c0, true);                        // yes read incrementing
    channel_config_set_write_increment(&c0, false);                      // no write incrementing
    channel_config_set_dreq(&c0, DREQ_PIO0_TX2) ;                        // DREQ_PIO0_TX2 pacing (FIFO)
    channel_config_set_chain_to(&c0, pxl_chan_1);                        // chain to other channel

    dma_channel_configure(
        pxl_chan_0,                 // Channel to be configured
        &c0,                        // The configuration we just created
        &pio->txf[pxl_sm],          // write address (RGB PIO TX FIFO)
        &DLP_data_array,            // The initial read address (pixel color array)
        TXCOUNT,                    // Number of transfers; in this case each is 1 byte.
        false                       // Don't start immediately.
    );

    // Channel One (reconfigures the first channel)
    dma_channel_config c1 = dma_channel_get_default_config(pxl_chan_1);   // default configs
    channel_config_set_transfer_data_size(&c1, DMA_SIZE_32);              // 32-bit txfers
    channel_config_set_read_increment(&c1, false);                        // no read incrementing
    channel_config_set_write_increment(&c1, false);                       // no write incrementing
    channel_config_set_chain_to(&c1, pxl_chan_0);                         // chain to other channel

    dma_channel_configure(
        pxl_chan_1,                         // Channel to be configured
        &c1,                                // The configuration we just created
        &dma_hw->ch[pxl_chan_0].read_addr,  // Write address (channel 0 read address)
        &address_pointer,                   // Read address (POINTER TO AN ADDRESS)
        1,                                  // Number of transfers, in this case each is 4 byte
        false                               // Don't start immediately.
    );

    /////////////////////////////////////////////////////////////////////////////////////////////////////
    /////////////////////////////////////////////////////////////////////////////////////////////////////

    // Initialize PIO state machine counters. This passes the information to the state machines
    // that they retrieve in the first 'pull' instructions, before the .wrap_target directive
    // in the assembly. Each uses these values to initialize some counting registers.
    pio_sm_put_blocking(pio, hsync_sm, H_ACTIVE);
    pio_sm_put_blocking(pio, vsync_sm, V_ACTIVE);
    pio_sm_put_blocking(pio, pxl_sm, DATAEM_CMD_ACTIVE);
    pio_sm_put_blocking(pio, clk_sm, DATAEM_CMD_ACTIVE);


    // Start the two pio machine IN SYNC
    // Note that the PXL state machine is running at full speed,
    // so synchronization doesn't matter for that one. But, we'll
    // start them all simultaneously anyway.
    pio_enable_sm_mask_in_sync(pio, ((1u << hsync_sm) | (1u << vsync_sm) | (1u << pxl_sm) | (1u << clk_sm)));

    // Start DMA channel 0. Once started, the contents of the pixel data array
    // will be continously DMA's to the PIO machines that are driving the screen.
    // To change the contents of the screen, we need only change the contents
    // of that array.
    dma_start_channel_mask((1u << pxl_chan_0)) ;


    ////////////////////////////////////////////////////////////////////////////////////////////////
    // ===================================== DLPC1438 stuff ========================================
    ////////////////////////////////////////////////////////////////////////////////////////////////
    
    gpio_init(LED_PIN_G);
    gpio_set_dir(LED_PIN_G, GPIO_OUT);
    gpio_init(LED_PIN_R);
    gpio_set_dir(LED_PIN_R, GPIO_OUT);
    for (int i = 0; i < 5; i++) {
        printf("Blinking!\r\n");
        gpio_put(LED_PIN_G, 0);
        sleep_ms(250);
        gpio_put(LED_PIN_G, 1);
        sleep_ms(1000);
    }

      printf("%x:%x:%x:%x:%x\n", DLP_data_array[0], DLP_data_array[1], DLP_data_array[2], DLP_data_array[3], DLP_data_array[115100]); // TODO: REMOVE
    
    initialise_DLPC();

    configure_i2c();  // set up i2c hardware
    check_i2c_communication();  // check that we can talk to DLPC1438

    // optional test commands
    intialise_DLP_test_pattern();
    sleep_ms(500);  // just wait and check if test pattern appears
    //curtain_flood_exposure(100, 3);  // flash at max brightness a few times (for testing)
    switch_projector_mode(STANDBY); // stop illumination and be in long term stable mode
    sleep_ms(300);

    // prepare printer for external print mode

    configure_external_print();
    switch_projector_mode(EXTERNALPRINT);
    set_illumination_PWM(0xB4);
    set_image_orientation(false, false);

    ///////// EXTERNAL PRINT MODE SECTION
    // programming guide section 3.3.1 ("3D Print Procedure Without FPGA Front-End")


    // -- setup phase -----------
    printf("\n>> EXTERNAL PRINT SETUP <<\n\n");
    configure_external_print(); 
    switch_projector_mode(EXTERNALPRINT); 
    sleep_ms(200); // For now just wait a bit. Ideally: detect SYSTEM_READY (GPIO_06; not connected)
    set_illumination_PWM(0xB4);  
    set_image_orientation(false, false);

    printf("Checking light state...");
    switch_light_state(ON);   // turn on the projector and show whatever is in image buffer

    // -- loop phase ---------
    printf("\n>> EXTERNAL PRINT LOOP <<\n\n");
    //checkerboard_PIO(); // send video data [A]
    // // TODO: remove the sanity check below
    printf("%x:%x:%x:%x:%x\n", DLP_data_array[0], DLP_data_array[12], DLP_data_array[6000], DLP_data_array[100000], DLP_data_array[72]);
    // switch_light_state(ON);   // turn on the projector and show whatever is in image buffer
    // // -> go to line above loop back to [A]
    
    sleep_ms(15000); // TODO: remove

    switch_light_state(OFF);
    sleep_ms(1000);
    
    switch_projector_mode(STANDBY); // stop illumination and be in long term stable mode
    
    printf("\ndone.");
}

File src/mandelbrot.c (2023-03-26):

/**
 * Hunter Adams (vha3@cornell.edu)
 * 
 * Mandelbrot set calculation and visualization
 * Uses PIO-assembly VGA driver
 *
 * HARDWARE CONNECTIONS
 *  - GPIO 16 ---> VGA Hsync
 *  - GPIO 17 ---> VGA Vsync
 *  - GPIO 18 ---> 330 ohm resistor ---> VGA Red
 *  - GPIO 19 ---> 330 ohm resistor ---> VGA Green
 *  - GPIO 20 ---> 330 ohm resistor ---> VGA Blue
 *  - RP2040 GND ---> VGA GND
 *
 * RESOURCES USED
 *  - PIO state machines 0, 1, and 2 on PIO instance 0
 *  - DMA channels 0 and 1
 *  - 153.6 kBytes of RAM (for pixel color data)
 *
 */
#include <stdio.h>
#include "pico/stdlib.h"
#include "hardware/pio.h"
#include "hardware/dma.h"
// Our assembled programs:
// Each gets the name <pio_filename.pio.h>
#include "hsync.pio.h"
#include "vsync.pio.h"
#include "rgb.pio.h"


// VGA timing constants
#define H_ACTIVE   655    // (active + frontporch - 1) - one cycle delay for mov
#define V_ACTIVE   479    // (active - 1)
#define RGB_ACTIVE 319    // (horizontal active)/2 - 1
// #define RGB_ACTIVE 639 // change to this if 1 pixel/byte

// Length of the pixel array, and number of DMA transfers
#define TXCOUNT 153600 // Total pixels/2 (since we have 2 pixels per byte)

// Pixel color array that is DMA's to the PIO machines and
// a pointer to the ADDRESS of this color array.
// Note that this array is automatically initialized to all 0's (black)
unsigned char vga_data_array[TXCOUNT];
char * address_pointer = &vga_data_array[0] ;

// Give the I/O pins that we're using some names that make sense
#define HSYNC     13
#define VSYNC     11
#define RED_PIN   18
#define GREEN_PIN 19
#define BLUE_PIN  20

// We can only produce 8 colors, so let's give them readable names
#define BLACK   0
#define RED     1
#define GREEN   2
#define YELLOW  3
#define BLUE    4
#define MAGENTA 5
#define CYAN    6
#define WHITE   7


// A function for drawing a pixel with a specified color.
// Note that because information is passed to the PIO state machines through
// a DMA channel, we only need to modify the contents of the array and the
// pixels will be automatically updated on the screen.
void drawPixel(int x, int y, char color) {
    // Range checks
    if (x > 639) x = 639 ;
    if (x < 0) x = 0 ;
    if (y < 0) y = 0 ;
    if (y > 479) y = 479 ;

    // Which pixel is it?
    int pixel = ((640 * y) + x) ;

    // Is this pixel stored in the first 3 bits
    // of the vga data array index, or the second
    // 3 bits? Check, then mask.
    if (pixel & 1) {
        vga_data_array[pixel>>1] |= (color << 3) ;
    }
    else {
        vga_data_array[pixel>>1] |= (color) ;
    }
}
////////////////////////////////////////////////////////////////////////////////////////////////////
/////////////// Stuff for Mandelbrot ///////////////////////////////////////////////////////////////
////////////////////////////////////////////////////////////////////////////////////////////////////
// Fixed point data type
typedef signed int fix28 ;
#define multfix28(a,b) ((fix28)(((( signed long long)(a))*(( signed long long)(b)))>>28)) 
#define float2fix28(a) ((fix28)((a)*268435456.0f)) // 2^28
#define fix2float28(a) ((float)(a)/268435456.0f) 
#define int2fix28(a) ((a)<<28)
// the fixed point value 4
#define FOURfix28 0x40000000 
#define SIXTEENTHfix28 0x01000000
#define ONEfix28 0x10000000

// Maximum number of iterations
#define max_count 1000

// Mandelbrot values
fix28 Zre, Zim, Cre, Cim ;
fix28 Zre_sq, Zim_sq ;

int i, j, count, total_count ;

fix28 x[640] ;
fix28 y[480] ;

////////////////////////////////////////////////////////////////////////////////////////////////////

int main() {

    // Initialize stdio
    stdio_init_all();

    // Choose which PIO instance to use (there are two instances, each with 4 state machines)
    PIO pio = pio0;

    // Our assembled program needs to be loaded into this PIO's instruction
    // memory. This SDK function will find a location (offset) in the
    // instruction memory where there is enough space for our program. We need
    // to remember these locations!
    //
    // We only have 32 instructions to spend! If the PIO programs contain more than
    // 32 instructions, then an error message will get thrown at these lines of code.
    //
    // The program name comes from the .program part of the pio file
    // and is of the form <program name_program>
    uint hsync_offset = pio_add_program(pio, &hsync_program);
    uint vsync_offset = pio_add_program(pio, &vsync_program);
    uint rgb_offset = pio_add_program(pio, &rgb_program);

    // Manually select a few state machines from pio instance pio0.
    uint hsync_sm = 0;
    uint vsync_sm = 1;
    uint rgb_sm = 2;

    // Call the initialization functions that are defined within each PIO file.
    // Why not create these programs here? By putting the initialization function in
    // the pio file, then all information about how to use/setup that state machine
    // is consolidated in one place. Here in the C, we then just import and use it.
    hsync_program_init(pio, hsync_sm, hsync_offset, HSYNC);
    vsync_program_init(pio, vsync_sm, vsync_offset, VSYNC);
    rgb_program_init(pio, rgb_sm, rgb_offset, RED_PIN);


    /////////////////////////////////////////////////////////////////////////////////////////////////////
    // ===========================-== DMA Data Channels =================================================
    /////////////////////////////////////////////////////////////////////////////////////////////////////

    // DMA channels - 0 sends color data, 1 reconfigures and restarts 0
    int rgb_chan_0 = 0;
    int rgb_chan_1 = 1;

    // Channel Zero (sends color data to PIO VGA machine)
    dma_channel_config c0 = dma_channel_get_default_config(rgb_chan_0);  // default configs
    channel_config_set_transfer_data_size(&c0, DMA_SIZE_8);              // 8-bit txfers
    channel_config_set_read_increment(&c0, true);                        // yes read incrementing
    channel_config_set_write_increment(&c0, false);                      // no write incrementing
    channel_config_set_dreq(&c0, DREQ_PIO0_TX2) ;                        // DREQ_PIO0_TX2 pacing (FIFO)
    channel_config_set_chain_to(&c0, rgb_chan_1);                        // chain to other channel

    dma_channel_configure(
        rgb_chan_0,                 // Channel to be configured
        &c0,                        // The configuration we just created
        &pio->txf[rgb_sm],          // write address (RGB PIO TX FIFO)
        &vga_data_array,            // The initial read address (pixel color array)
        TXCOUNT,                    // Number of transfers; in this case each is 1 byte.
        false                       // Don't start immediately.
    );
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

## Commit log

2023-03-25 Clean up board silkscreen
    Cleaned up silkscreen and added schematic pdf
    [micromirror-board-controller.kicad_pcb, micromirror-board-controller.kicad_sch]
2023-03-26 Rearrangement of PCB traces and length matching
    Needed to rearrange pins. Matched trace lengths; probably overkill.
    [micromirror-board-controller.kicad_pcb, micromirror-board-controller.kicad_sch]
2023-03-26 Finalised length-matched PCB
    Fixed final few remaining traces with the new board layout.
    [micromirror-board-controller.kicad_pcb, micromirror-board-controller.kicad_sch]
2023-03-28 Set up pins and state machines
    Set up the correct pinout, configure the 4 state machines. Basic (approximate) timings are in place but demo pixel data still needs to be generated.
    [DLP_pico.c]
2023-03-31 Move to USB-C connector
    Replacing the original type-A connector now a type-C connector. CC1/2 terminated with 5.1k.
    [micromirror-board-controller.kicad_pcb, micromirror-board-controller.kicad_sch]
2023-03-31 Add openMLA logo
    Added logo and fixed missing ground connection on FPC. Did some cleanup with DRC.
    [micromirror-board-controller.kicad_pcb]
2023-03-31 Add PCB preview image
2023-04-01 Add licence
    Add software and hardware licence. Added open hardware and licence info to PCB.
    [micromirror-board-controller.kicad_pcb]
2023-06-03 Complete schematic parts list
    Fix some parts without purchase link and clean up directory a bit.
    [micromirror-board-controller.kicad_sch]
2023-06-27 Improved USB lines connectivity
    Fixed the tricky blind SMD pad approach with cutout and backside wire connection. Added some 3D models for all board components. Reworked some silkscreen. Added a TX/RX serial connector for convenience
    [board-outline.FCStd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]
2023-07-15 Fix +12V pinout and revise board
    Fixed the 12V board pinout (apparently GND and VSUP are swapped). Some early code on talking to the DLPC1438; not all verified to be correct yet.
    [micromirror-board-controller.kicad_pcb, micromirror-board-controller.kicad_sch]
2024-01-05 Update source files
    [board-outline-stencil-buffer.step, micromirror-board-controller.kicad_sch]
2024-01-05 Functional startup code
    Tested startup cycle code in initialise_DLPC(). Confirmed to work with the parallel FPC interface on the development board.
2024-01-06 standby mode and early external print checks
2024-01-18 More functional I2C communication
2024-01-20 Clean up testpattern code
    After some testing I think the i2c responses for testpattern are valid, although the pattern is still not projected as expected. But at least I2C seems good now.
2024-01-21 Select correct LED and integrate more I2C settings
    Integrate findings from I2C commands sent and their values from the original anycubic board.
    [DLP_pico.c]
2024-01-22 Patch for HOST_IRQ detection
    Dirty fix for the HOST_IRQ detection which is unreliable due to different voltage levels of DLPC1438. Added some debugging changes which will be reverted later I suspect.
    [DLP_pico.c]
2024-01-23 Correct Basic code for External Print Mode
    To be perfectly honest, I am not sure why it is working now, but it was not working before. Maybe something was changed on the hardware side, but this correctly displays some kind of data from the parallel interface.
    [DLP_pico.c]
2024-01-25 Update image converter for 2-bit format
    Updated the python utilitty to convert grayscale tifs into the 2-bit format that can be used in the pico code.
2024-04-12 Add archiving message
    The repository will be renamed and archived. The replacement efforts will use the raspberry pi DPI capabilities instead.

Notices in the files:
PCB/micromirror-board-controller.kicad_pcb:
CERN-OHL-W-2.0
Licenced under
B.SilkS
